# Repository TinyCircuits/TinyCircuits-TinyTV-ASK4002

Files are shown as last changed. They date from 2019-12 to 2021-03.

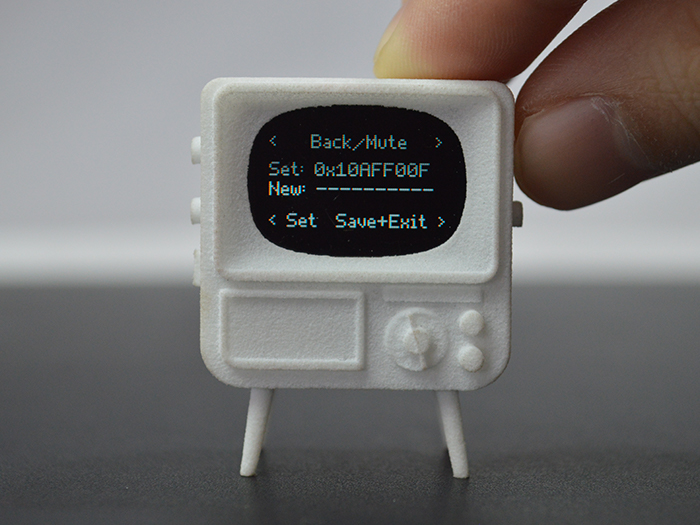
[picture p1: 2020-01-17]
images/TinyTV-Settings-Tutorial-Image-03.jpg

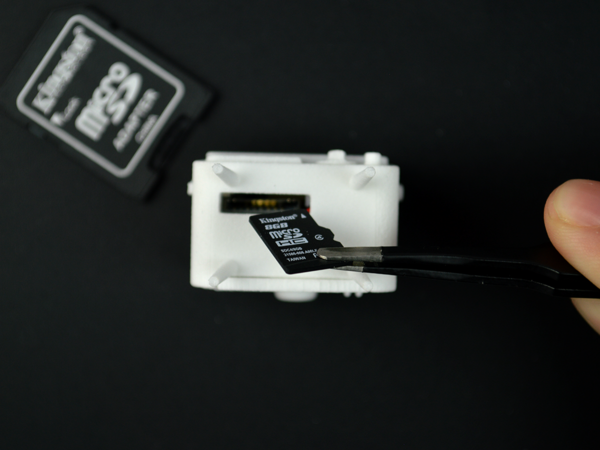
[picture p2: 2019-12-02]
images/TinyTV-Tutorial-Image-12.png

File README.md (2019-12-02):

# TinyCircuits TinyTV
# ASK4002

The design files are located under design_files/ for the TinyTV Remote, other design files can be found under the individual components' name on our GitHub. This Repo contains any files or documentation specific to the TinyTV.

Format is in Cadsoft Eagle format - Eagle version 6.2 was used for the original design.

For more infomation on this, check out the product page at TinyCircuits.com

# License:

Design by TinyCircuits.
All design files are released under the Creative Commons Attribution Share-Alike 3.0 License, see the following link for details: http://creativecommons.org/licenses/by-sa/3.0

All text above must be included in any redistribution or derived design

This project uses designs and concepts developed as part of the Arduino project and the LilyPad project.  The TinyCircuits design files themselves (schematics, PCB and libraries) are not directly derived from these works' design files and have been created new, however the concepts and basic architecture behind the TinyDuino and TinyLily products are derived and we thank the hard work of the organizations below for their contributions to open-source hardware:
  
Original Arduino Uno Design by Team Arduino

LilyPad Arduino Design by Leah Buechley and Sparkfun Electronics

Please support the open-source hardware community

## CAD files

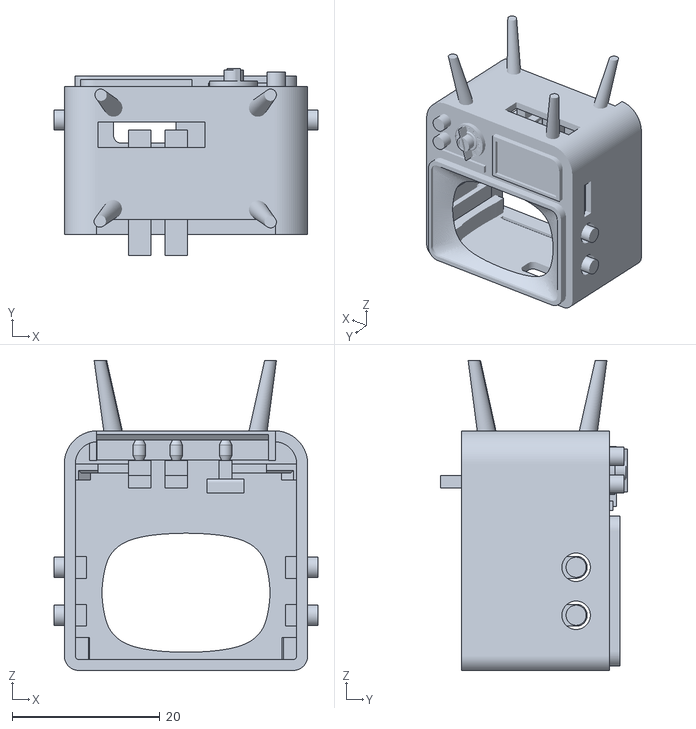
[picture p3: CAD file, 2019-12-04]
res/TinyTV_3D_files/TinyTVBodyV7.stl
35.7 x 25.4 x 42.0

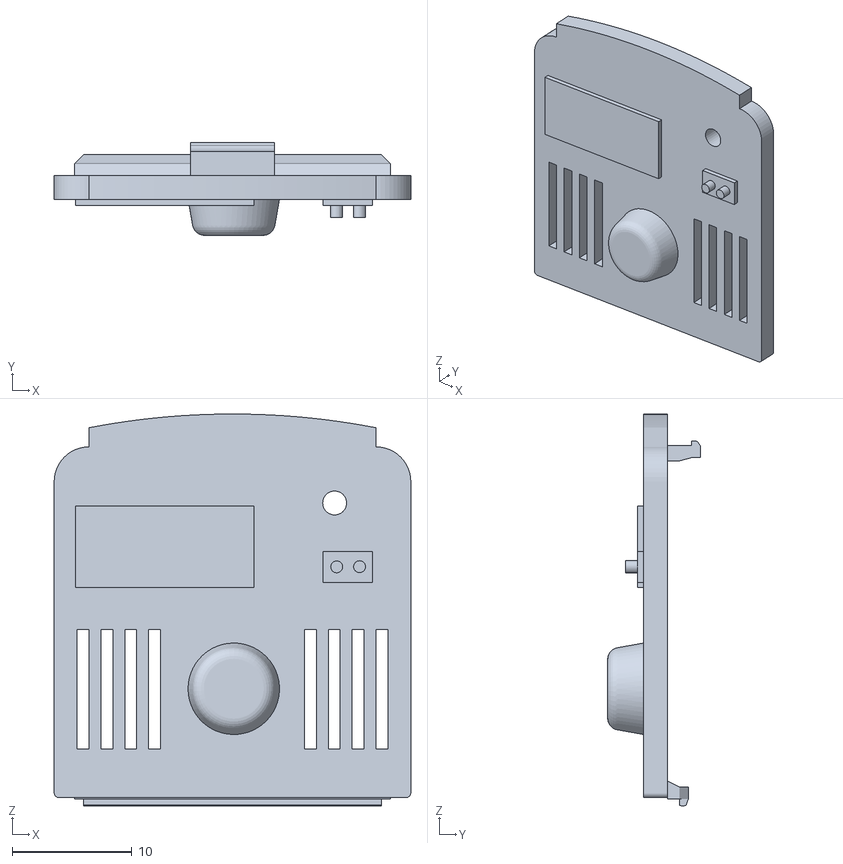
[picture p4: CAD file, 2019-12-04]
res/TinyTV_3D_files/RearPanelV7.stl
29.8 x 7.75 x 32.8

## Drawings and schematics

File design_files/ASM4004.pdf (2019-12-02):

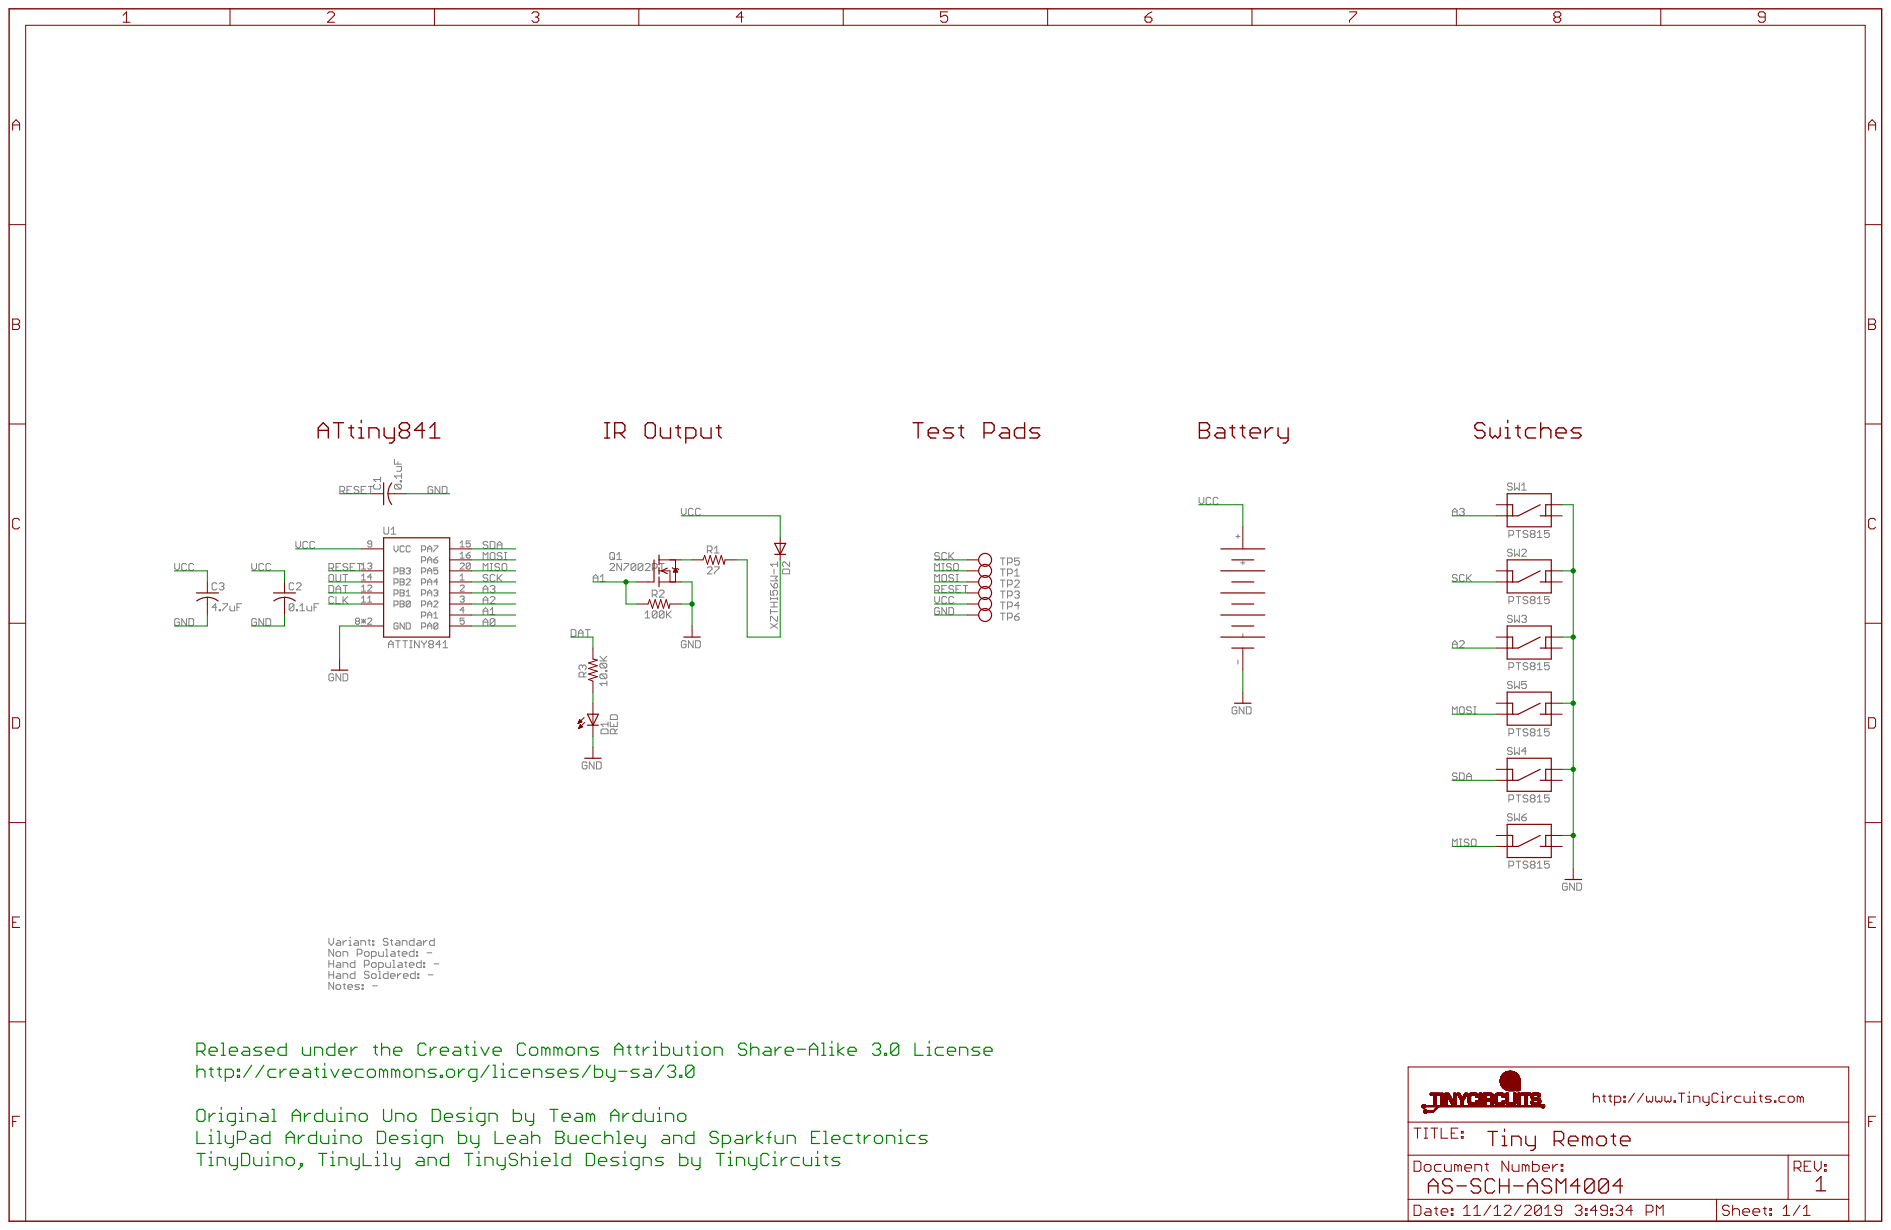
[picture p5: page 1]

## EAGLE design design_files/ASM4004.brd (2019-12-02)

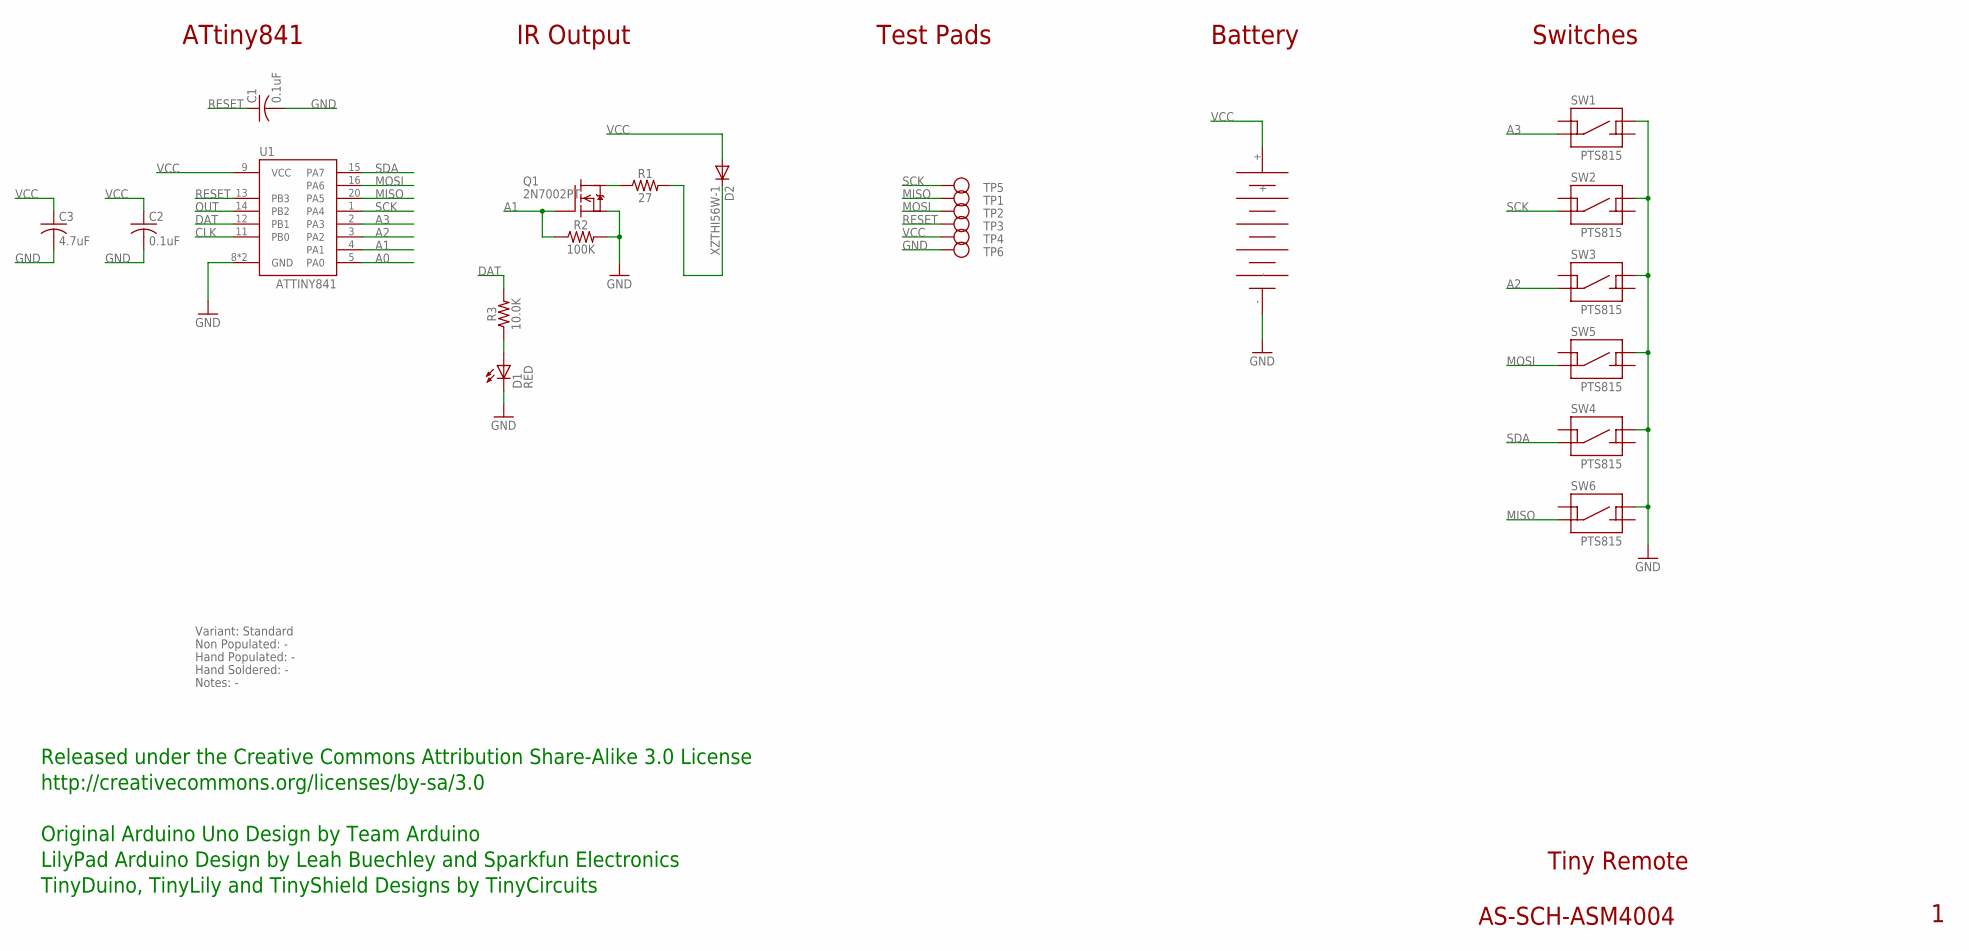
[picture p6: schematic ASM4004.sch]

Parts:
C1: 0.1uF; C0402; PARTNO AS-ITM-00008
C2: 0.1uF; C0402
C3: 4.7uF; C0402; PARTNO AS-ITM-00242
D1: RED; 0402_LED; PARTNO AS-ITM-00057
D2: XZTHI56W-1; LED_SIDE_3.0X1.0; PARTNO AS-ITM-00551
J2: 1225; COIN_1220_SMD; PARTNO AS-ITM-00468
Q1: 2N7002PT; SOT-416
R1: 27; 0402; PARTNO AS-ITM-00240
R2: 100K; 0402
R3: 10.0K; 0402; PARTNO AS-ITM-00032
SW1, SW2, SW3, SW4, SW5, SW6: PTS815; PARTNO AS-ITM-00544
TP1, TP2, TP3, TP4, TP5, TP6: TEST_POINT; TEST_POINT_1MM
U1: ATTINY841; VQFN-20

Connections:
A0: U1.5 (PA0)
A1: Q1.1 (G), R2.1, U1.4 (PA1)
A2: SW3.1, U1.3 (PA2)
A3: SW1.1, U1.2 (PA3)
CLK: U1.11 (PB0)
DAT: R3.2, U1.12 (PB1)
GND: C1.2, C2.2, C3.2, D1.2 (C), J2.-, Q1.2 (S), R2.2, SW1.4, SW2.4, SW3.4, SW4.4, SW5.4, SW6.4, TP6.P$1, U1.8 (GND), U1.PAD (GND)
MISO: SW6.1, TP1.P$1, U1.20 (PA5)
MOSI: SW5.1, TP2.P$1, U1.16 (PA6)
unnamed: Q1.3 (D), R1.1
unnamed: D2.C, R1.2
unnamed: D1.1 (A), R3.1
OUT: U1.14 (PB2)
RESET: C1.1, TP3.P$1, U1.13 (PB3)
SCK: SW2.1, TP5.P$1, U1.1 (PA4)
SDA: SW4.1, U1.15 (PA7)
VCC: C2.1, C3.1, D2.A, J2.+, TP4.P$1, U1.9 (VCC)

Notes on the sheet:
Tiny Remote
AS-SCH-ASM4004
Test Pads
ATtiny841
Battery
IR Output
Variant: Standard
Non Populated: -
Hand Populated: -
Hand Soldered: -
Notes: -
Switches
Released under the Creative Commons Attribution Share-Alike 3.0 License
http://creativecommons.org/licenses/by-sa/3.0
Original Arduino Uno Design by Team Arduino
TinyDuino, TinyLily and TinyShield Designs by TinyCircuits
LilyPad Arduino Design by Leah Buechley and Sparkfun Electronics

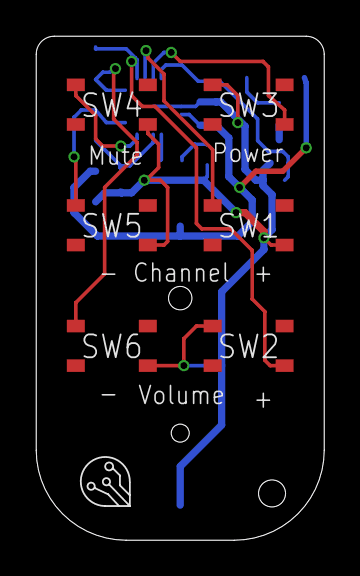
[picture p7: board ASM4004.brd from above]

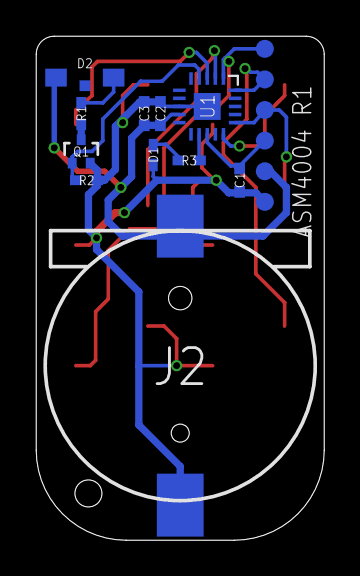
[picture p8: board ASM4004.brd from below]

Board: 2 copper layers, 16.0 x 28.0 mm, 24 parts (17 on the bottom side), 14 nets.

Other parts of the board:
U$1: DOCFIELD-TINYCIRCUITS-PCB

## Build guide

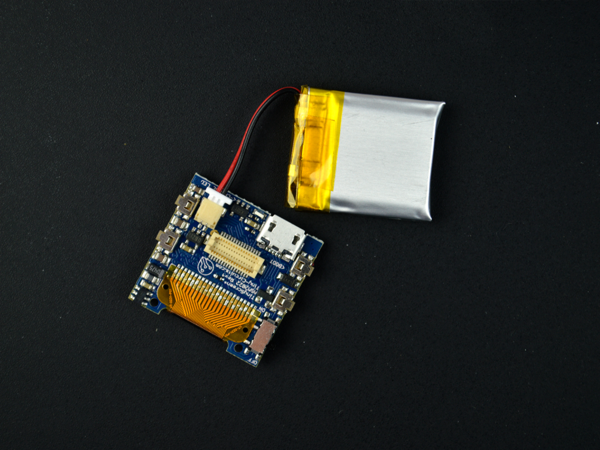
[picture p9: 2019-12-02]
images/TinyTV-Tutorial-Image-03.png

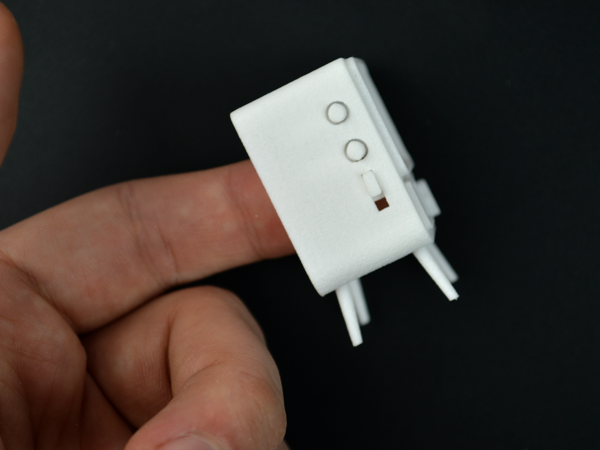
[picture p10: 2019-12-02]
images/TinyTV-Tutorial-Image-06.png

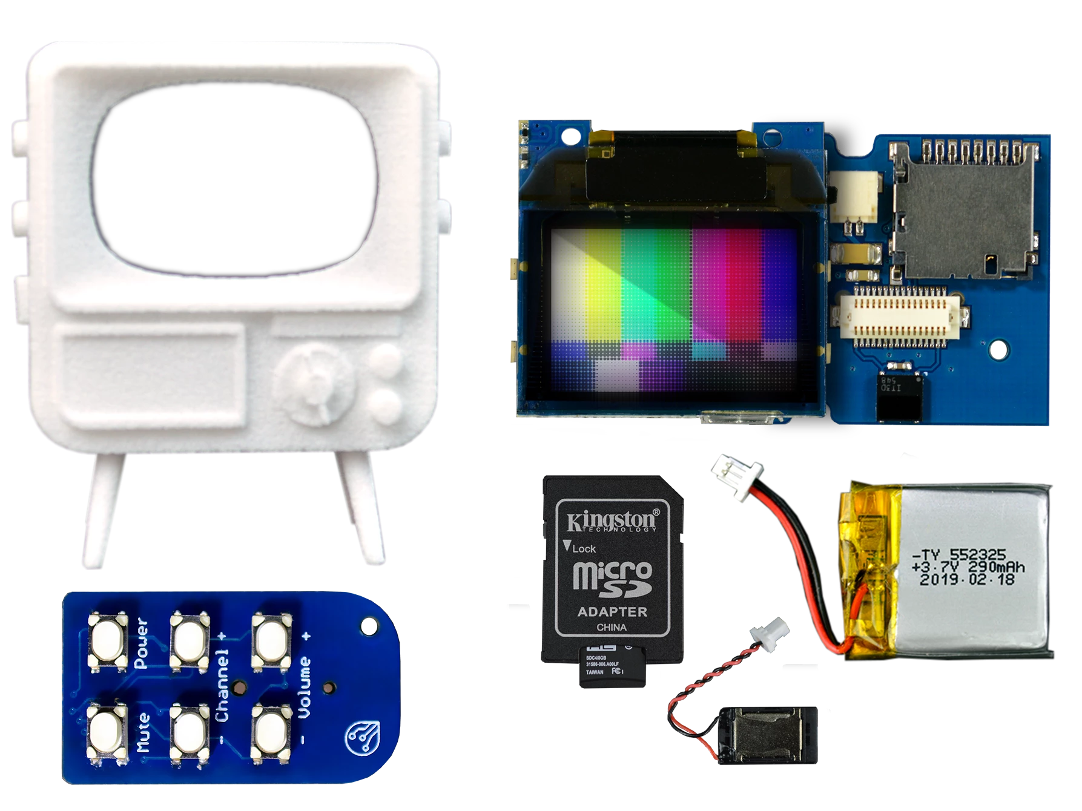
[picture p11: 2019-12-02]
images/TinyTV-Tutorial-Image-01.png

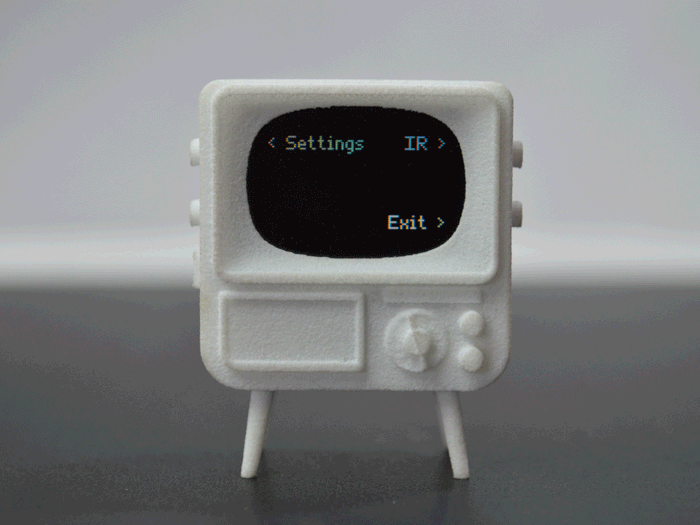
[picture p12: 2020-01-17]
images/TinyTV-Settings-Tutorial-Animation-01.gif

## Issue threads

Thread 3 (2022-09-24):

GCLK was not declared in scope.

patrick99e99, 2022-09-24:
I got your tinytv kit, and am following along your instructions:
http://learn.tinycircuits.com/Kits/Tiny-Video-Program/

When I open TinyTV.ino and click "verify" it says:
```
Arduino: 1.8.19 (Mac OS X), Board: "Arduino Uno"

/Users/patrick/Downloads/TinyTV/audio.ino: In function 'void tcConfigure(uint32_t)':
audio:7:3: error: 'GCLK' was not declared in this scope
   GCLK->CLKCTRL.reg = (uint16_t) (GCLK_CLKCTRL_CLKEN | GCLK_CLKCTRL_GEN_GCLK0 | GCLK_CLKCTRL_ID(GCM_TC4_TC5)) ;
   ^~~~
/Users/patrick/Downloads/TinyTV/audio.ino:7:3: note: suggested alternative: 'SCL'
   GCLK->CLKCTRL.reg = (uint16_t) (GCLK_CLKCTRL_CLKEN | GCLK_CLKCTRL_GEN_GCLK0 | GCLK_CLKCTRL_ID(GCM_TC4_TC5)) ;
   ^~~~
   SCL
audio:7:35: error: 'GCLK_CLKCTRL_CLKEN' was not declared in this scope
   GCLK->CLKCTRL.reg = (uint16_t) (GCLK_CLKCTRL_CLKEN | GCLK_CLKCTRL_GEN_GCLK0 | GCLK_CLKCTRL_ID(GCM_TC4_TC5)) ;
                                   ^~~~~~~~~~~~~~~~~~
audio:7:56: error: 'GCLK_CLKCTRL_GEN_GCLK0' was not declared in this scope
   GCLK->CLKCTRL.reg = (uint16_t) (GCLK_CLKCTRL_CLKEN | GCLK_CLKCTRL_GEN_GCLK0 | GCLK_CLKCTRL_ID(GCM_TC4_TC5)) ;
                                                        ^~~~~~~~~~~~~~~~~~~~~~
audio:7:97: error: 'GCM_TC4_TC5' was not declared in this scope
   GCLK->CLKCTRL.reg = (uint16_t) (GCLK_CLKCTRL_CLKEN | GCLK_CLKCTRL_GEN_GCLK0 | GCLK_CLKCTRL_ID(GCM_TC4_TC5)) ;
                                                                                                 ^~~~~~~~~~~
audio:7:81: error: 'GCLK_CLKCTRL_ID' was not declared in this scope
   GCLK->CLKCTRL.reg = (uint16_t) (GCLK_CLKCTRL_CLKEN | GCLK_CLKCTRL_GEN_GCLK0 | GCLK_CLKCTRL_ID(GCM_TC4_TC5)) ;
                                                                                 ^~~~~~~~~~~~~~~
audio:13:3: error: 'TC5' was not declared in this scope
   TC5->COUNT16.CTRLA.reg |= TC_CTRLA_MODE_COUNT16;
   ^~~
/Users/patrick/Downloads/TinyTV/audio.ino:13:3: note: suggested alternative: 'RC5'
   TC5->COUNT16.CTRLA.reg |= TC_CTRLA_MODE_COUNT16;
   ^~~
   RC5
audio:13:29: error: 'TC_CTRLA_MODE_COUNT16' was not declared in this scope
   TC5->COUNT16.CTRLA.reg |= TC_CTRLA_MODE_COUNT16;
                             ^~~~~~~~~~~~~~~~~~~~~
audio:16:29: error: 'TC_CTRLA_WAVEGEN_MFRQ' was not declared in this scope
   TC5->COUNT16.CTRLA.reg |= TC_CTRLA_WAVEGEN_MFRQ;
                             ^~~~~~~~~~~~~~~~~~~~~
audio:18:29: error: 'TC_CTRLA_PRESCALER_DIV1' was not declared in this scope
   TC5->COUNT16.CTRLA.reg |= TC_CTRLA_PRESCALER_DIV1;
                             ^~~~~~~~~~~~~~~~~~~~~~~
audio:20:40: error: 'SystemCoreClock' was not declared in this scope
   TC5->COUNT16.CC[0].reg = (uint16_t) (SystemCoreClock / sampleRate - 1);
                                        ^~~~~~~~~~~~~~~
audio:24:19: error: 'TC5_IRQn' was not declared in this scope
   NVIC_DisableIRQ(TC5_IRQn);
                   ^~~~~~~~
audio:24:3: error: 'NVIC_DisableIRQ' was not declared in this scope
   NVIC_DisableIRQ(TC5_IRQn);
   ^~~~~~~~~~~~~~~
audio:25:3: error: 'NVIC_ClearPendingIRQ' was not declared in this scope
   NVIC_ClearPendingIRQ(TC5_IRQn);
   ^~~~~~~~~~~~~~~~~~~~
audio:26:3: error: 'NVIC_SetPriority' was not declared in this scope
   NVIC_SetPriority(TC5_IRQn, 0);
   ^~~~~~~~~~~~~~~~
audio:27:3: error: 'NVIC_EnableIRQ' was not declared in this scope
   NVIC_EnableIRQ(TC5_IRQn);
   ^~~~~~~~~~~~~~
/Users/patrick/Downloads/TinyTV/audio.ino: In function 'bool tcIsSyncing()':
audio:37:10: error: 'TC5' was not declared in this scope
   return TC5->COUNT16.STATUS.reg & TC_STATUS_SYNCBUSY;
          ^~~
/Users/patrick/Downloads/TinyTV/audio.ino:37:10: note: suggested alternative: 'RC5'
   return TC5->COUNT16.STATUS.reg & TC_STATUS_SYNCBUSY;
          ^~~
          RC5
audio:37:36: error: 'TC_STATUS_SYNCBUSY' was not declared in this scope
   return TC5->COUNT16.STATUS.reg & TC_STATUS_SYNCBUSY;
                                    ^~~~~~~~~~~~~~~~~~
/Users/patrick/Downloads/TinyTV/audio.ino: In function 'void tcStartCounter()':
audio:44:3: error: 'TC5' was not declared in this scope
   TC5->COUNT16.CTRLA.reg |= TC_CTRLA_ENABLE;
   ^~~
/Users/patrick/Downloads/TinyTV/audio.ino:44:3: note: suggested alternative: 'RC5'
   TC5->COUNT16.CTRLA.reg |= TC_CTRLA_ENABLE;
   ^~~
   RC5
audio:44:29: error: 'TC_CTRLA_ENABLE' was not declared in this scope
   TC5->COUNT16.CTRLA.reg |= TC_CTRLA_ENABLE;
                             ^~~~~~~~~~~~~~~
/Users/patrick/Downloads/TinyTV/audio.ino: In function 'void tcReset()':
audio:51:3: error: 'TC5' was not declared in this scope
   TC5->COUNT16.CTRLA.reg = TC_CTRLA_SWRST;
   ^~~
/Users/patrick/Downloads/TinyTV/audio.ino:51:3: note: suggested alternative: 'RC5'
   TC5->COUNT16.CTRLA.reg = TC_CTRLA_SWRST;
   ^~~
   RC5
audio:51:28: error: 'TC_CTRLA_SWRST' was not declared in this scope
   TC5->COUNT16.CTRLA.reg = TC_CTRLA_SWRST;
                            ^~~~~~~~~~~~~~
/Users/patrick/Downloads/TinyTV/audio.ino: In function 'void tcDisable()':
audio:59:3: error: 'TC5' was not declared in this scope
   TC5->COUNT16.CTRLA.reg &= ~TC_CTRLA_ENABLE;
   ^~~
/Users/patrick/Downloads/TinyTV/audio.ino:59:3: note: suggested alternative: 'RC5'
   TC5->COUNT16.CTRLA.reg &= ~TC_CTRLA_ENABLE;
   ^~~
   RC5
audio:59:30: error: 'TC_CTRLA_ENABLE' was not declared in this scope
   TC5->COUNT16.CTRLA.reg &= ~TC_CTRLA_ENABLE;
                              ^~~~~~~~~~~~~~~
/Users/patrick/Downloads/TinyTV/audio.ino: In function 'void Audio_Handler()':
audio:72:10: error: 'DAC' was not declared in this scope
   while (DAC->STATUS.bit.SYNCBUSY == 1);
          ^~~
/Users/patrick/Downloads/TinyTV/audio.ino:72:10: note: suggested alternative: 'DEC'
   while (DAC->STATUS.bit.SYNCBUSY == 1);
          ^~~
          DEC
audio:81:3: error: 'DAC' was not declared in this scope
   DAC->DATA.reg =  dacOut;
   ^~~
/Users/patrick/Downloads/TinyTV/audio.ino:81:3: note: suggested alternative: 'DEC'
   DAC->DATA.reg =  dacOut;
   ^~~
   DEC
audio:94:3: error: 'TC5' was not declared in this scope
   TC5->COUNT16.INTFLAG.bit.MC0 = 1;
   ^~~
/Users/patrick/Downloads/TinyTV/audio.ino:94:3: note: suggested alternative: 'RC5'
   TC5->COUNT16.INTFLAG.bit.MC0 = 1;
   ^~~
   RC5
/Users/patrick/Downloads/TinyTV/settingsMenu.ino: In function 'void readCodes()':
settingsMenu:11:3: error: 'SerialUSB' was not declared in this scope
   SerialUSB.print("Opening IRCodes.txt.. ");
   ^~~~~~~~~
/Users/patrick/Downloads/TinyTV/settingsMenu.ino:11:3: note: suggested alternative: 'Serial'
   SerialUSB.print("Opening IRCodes.txt.. ");
   ^~~~~~~~~
   Serial
/Users/patrick/Downloads/TinyTV/settingsMenu.ino: In function 'void readSettings()':
settingsMenu:141:3: error: 'SerialUSB' was not declared in this scope
   SerialUSB.print("Opening Settings.txt.. ");
   ^~~~~~~~~
/Users/patrick/Downloads/TinyTV/settingsMenu.ino:141:3: note: suggested alternative: 'Serial'
   SerialUSB.print("Opening Settings.txt.. ");
   ^~~~~~~~~
   Serial
In file included from /Users/patrick/Downloads/TinyTV/videoPlayer.ino:33:0:
/Users/patrick/Downloads/TinyTV/videoPlayerEffects.h: In function 'void showStaticEffect()':
videoPlayerEffects.h:98:27: error: 'SysTick' was not declared in this scope
     uint8_t currentRand = SysTick->VAL;
                           ^~~~~~~
/Users/patrick/Downloads/TinyTV/videoPlayerEffects.h: In function 'void tinyTVtubeOff()':
videoPlayerEffects.h:188:33: error: 'SysTick' was not declared in this scope
           uint8_t currentRand = SysTick->VAL;
                                 ^~~~~~~
videoPlayerEffects.h:211:35: error: 'SysTick' was not declared in this scope
             uint8_t currentRand = SysTick->VAL;
                                   ^~~~~~~
/Users/patrick/Downloads/TinyTV/videoPlayer.ino: In function 'void playVideo()':
videoPlayer:194:59: error: 'SysTick' was not declared in this scope
           audioBuffer2[i] += (int8_t)((uint8_t)(((uint8_t)SysTick->VAL & 0x7F) | ((uint8_t)(SysTick->VAL << 7) & 0x80))) / 2;
                                                           ^~~~~~~
videoPlayer:202:59: error: 'SysTick' was not declared in this scope
           audioBuffer1[i] += (int8_t)((uint8_t)(((uint8_t)SysTick->VAL & 0x7F) | ((uint8_t)(SysTick->VAL << 7) & 0x80))) / 2;
                                                           ^~~~~~~
exit status 1
'GCLK' was not declared in this scope

This report would have more information with
"Show verbose output during compilation"
option enabled in File -> Preferences.
```

Also, when I go under Tools > Board, there is no TinyScreen+ option ...  And there is no `COM##(TinyScreen+)` option under port.

When I plug in the usb cable connected to the TV, I see an option under port appear `/dev/cu.usbmodem1101`

When I click board info I get:
```
BN: Unknown board
VID: 03EB
PID: 8009
SN: Upload any sketch to obtain it
```

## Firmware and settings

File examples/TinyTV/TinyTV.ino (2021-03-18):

//-------------------------------------------------------------------------------
//  TinyCircuits TinyTV Video Player
//
//  Changelog:
//  1.2.1 4 Jan 2021 - make lower left button configurable to "power off" or channel down
//  1.2.0 27 Nov 2019 - Add TinyTV mode with CRT effects, double buffered audio
//  1.1.0 15 Jul 2019 - Change to specifically support TinyScreen+ Video Player
//        Kit, adding IR receiver functionality and settings menu
//  1.0.3 15 Nov 2018 - Add option for TinyScreen+ button input
//  1.0.2 10 April 2017 - Cleanup, add messages about SD card/video detection
//  1.0.1 3 October 2016 - Add compatibility for new Arcade revision, change
//        folder structure for IDE compatibility
//  1.0.0 Initial release
//
//  Written by Ben Rose for TinyCircuits, http://TinyCircuits.com
//
//-------------------------------------------------------------------------------

#include <TinyScreen.h>
#include "SdFat.h"
#include <Wire.h>
#include <SPI.h>
#include "src/IRremote/IRremote.h"

// Default settings (Can be edited here or under the Settings menu on the TinyTV)
// To open TinyTV Settings: Turn TV off, then press and hold upper-right button
// while turning TV on. This should open the Settings & IR menu
long autoPlay = 1;
long showTimeBar = 1;
long loopVideo = 0;
long fullVolume = 1;
long tinyTVmode = 1;
long chanDwn = 0;

// IR NEC button codes (Can be edited here or under the IR menu on the TinyTV)
// The IR menu is found with the Settings menu. To toggle buttons for different
// functionality, open the IR menu, navigate to the desired button, press
// the button on the new remote, and save the NEC code.
long powerCode = 0x10AF8877;
long volUpCode = 0x10AF708F;
long volDownCode = 0x10AFB04F;
long chanUpCode = 0x10AF807F;
long chanDownCode = 0x10AF20DF;
long selectCode = 0x10AF00FF;
long returnCode = 0x10AFF00F;

int RECV_PIN = 3;

IRrecv irrecv(RECV_PIN);

TinyScreen display = TinyScreen(TinyScreenPlus);

SdFat sd;
SdFile dir;
SdFile vidFile;
uint8_t buffer[96 * 64 * 2];
uint16_t audioBuffer1[1024 * 2];
uint16_t audioBuffer2[1024 * 2];
int currentAudioBuffer = 0;
volatile int lastFilledAudioBuffer = 0;
volatile uint32_t sampleIndex = 0;

int currentFileNum = 0;
int doVideo = 0;
int foundValidVideo = 0;
char currentVideoName[50] = "No video found";

int printNicelyOffset = 0;
int printNicelyDir = 0;
unsigned long lastPrintNicelyOffsetChange = 0;
unsigned long printNicelyOffsetChangeInterval = 200;

volatile int volume = 5;
int maxVolume = 5;
int oldVolume = 5;

int isOff = false;


void setup(void) {
  analogWrite(A0, analogRead(A0));//Set audio output to avoid picking up noise, even if audio isn't used
  tcConfigure(30720);
  display.begin();
  display.setBitDepth(1);
  display.setFlip(true);
  display.setFont(thinPixel7_10ptFontInfo);
  display.initDMA();
  irrecv.enableIRIn(); // Start the receiver
  pinMode(RECV_PIN, INPUT_PULLUP);
  SPI.begin();
  delay(50);
  if (!sd.begin(10, SPI_FULL_SPEED)) {
    cardNotFound();
  }
  SPI.setClockDivider(0);
  if (display.getButtons(TSButtonUpperRight)) {
    delay(10);
    if (display.getButtons(TSButtonUpperRight)) {
      settingsMainMenu();
    }
  }
  readCodes();
  readSettings();
  if (!fullVolume) {
    volume = 3;
  }
  sd.vwd()->rewind();
  getNextFile();
  if (autoPlay || tinyTVmode) {
    startNewVideo();
  }
}

void loop() {
  if (tinyTVmode) {
    tinyTVloop();
  } else {
    videoPlayerLoop();
  }
}

void videoPlayerLoop() {

  decode_results results;

  long IRresult = 0;
  if (irrecv.decode(&results)) {
    irrecv.resume(); // Receive the next value
    //SerialUSB.print(results.decode_type);
    //SerialUSB.print(" ");
    //SerialUSB.print(results.bits);
    //SerialUSB.print(" ");
    //SerialUSB.println(results.value, HEX);
    IRresult = results.value;
  }
  if (!isOff && IRresult == volUpCode) {
    if (!isPaused())increaseVolumeRequest() ;
  }
  if (!isOff && IRresult == volDownCode) {
    if (!isPaused())decreaseVolumeRequest() ;
  }
  if (!isOff && (IRresult == chanUpCode || checkNewButtonPress(TSButtonLowerRight))) {
    if (isStopped() ) {
      //stopVideo();
      getNextFile();
      //startNewVideo();
    } else {
      seekForward();
    }
  }
  if (!isOff && IRresult == chanDownCode || checkNewButtonPress(TSButtonLowerLeft)) {
    if (isStopped() ) {
      //stopVideo();
      getPreviousFile();
      //startNewVideo();
    } else {
      seekBackward();
    }
  }
  if (!isOff && IRresult == selectCode || checkNewButtonPress(TSButtonUpperRight)) {
    if (isStopped()) {
      startNewVideo();
    } else {
      if (isPaused()) {
        requestUnPause();
      } else {
        requestPause();
        while (!isPaused())
          playVideo();
      }
    }
  }
  if (!isOff && IRresult == returnCode || checkNewButtonPress(TSButtonUpperLeft)) {
    if (!isStopped()) {
      stopVideo();
    }
  }
  if (IRresult == powerCode || checkNewButtonPress(TSButtonLowerLeft)) {
    if (!isOff) {
      if (!isStopped()) {
        requestPause();
        delay(10);
        display.endTransfer();
      }
      display.off();
      isOff = true;
    } else {
      display.on();
      if (!isStopped()) {
        display.goTo(0, 0);
        display.startData();
        requestUnPause();
      }
      isOff = false;
    }
  }
  if (doVideo  && !isOff && !isStopped()) {
    playVideo();
  }
  if (isStopped() && !isOff) {
    bufferVideoFrame();
    printNicely(currentVideoName);
    writeToDisplay();
  }
}


void tinyTVloop() {
  decode_results results;

  long IRresult = 0;
  if (irrecv.decode(&results)) {
    irrecv.resume(); // Receive the next value
    //SerialUSB.print(results.decode_type);
    //SerialUSB.print(" ");
    //SerialUSB.print(results.bits);
    //SerialUSB.print(" ");
    //SerialUSB.println(results.value, HEX);
    IRresult = results.value;
  }

  if (IRresult == volUpCode || checkNewButtonPress(TSButtonUpperRight)) {
    if (!isPaused())increaseVolumeRequest() ;
  }
  if (IRresult == volDownCode || checkNewButtonPress(TSButtonLowerRight)) {
    if (!isPaused())decreaseVolumeRequest() ;
  }
  if (IRresult == returnCode) {
    if (!isPaused())toggleMute();
  }
  if ((IRresult == chanUpCode || checkNewButtonPress(TSButtonUpperLeft)) && !isPaused()) {
    stopVideo();
    getNextFile();
    startNewVideo();
  }
if (IRresult == chanDownCode || (chanDwn && checkNewButtonPress(TSButtonLowerLeft)) && !isPaused()) {
    stopVideo();
    getPreviousFile();
    startNewVideo();
  }
  if (IRresult == powerCode || (!chanDwn && checkNewButtonPress(TSButtonLowerLeft))) {
    if (isPaused()) {
      display.on();
      display.goTo(0, 0);
      display.startData();
      requestUnPause();
    } else {
      requestPause();
      while (!isPaused())
        playVideo();
      delay(10);
      display.endTransfer();
      display.off();
    }
  }
  if (doVideo && !isPaused()) {
    playVideo();
  }
}

void bufferVideoFrame() {
  if (!vidFile.available())
    vidFile.rewind();
  vidFile.read(buffer, 96 * 64 * 2);
  vidFile.read((uint8_t*)audioBuffer1, 1024 * 2);
}

void writeToDisplay() {
  display.goTo(0, 0);
  display.startData();
  display.writeBuffer(buffer, 96 * 64 * 2);
  display.endTransfer();
}

void printCentered(int x, int y, char * stringToPrint) {
  int xPosition = x - ((int)display.getPrintWidth(stringToPrint) / 2);
  display.setCursor(xPosition, y);
  display.print(stringToPrint);
}

void displayCardNotFoundOptions() {
  display.clearScreen();
  display.setCursor(3, 8);
  display.print("< Settings ");
  display.setCursor(96 - 3 - display.getPrintWidth("IR >"), 8);
  display.print("IR >");
  display.setCursor(96 - 3 - display.getPrintWidth("Exit >"), 48);
  display.print("Exit >");
}

void settingsMainMenu() {
  displayCardNotFoundOptions();
  while (1) {
    if (checkNewButtonPress(TSButtonUpperRight)) {
      programCodes();
      displayCardNotFoundOptions();
    }
    if (checkNewButtonPress(TSButtonUpperLeft)) {
      changeSettings();
      displayCardNotFoundOptions();
    }
    if (checkNewButtonPress(TSButtonLowerRight)) {
      return;
    }
  }
}

void cardNotFound() {
  display.clearScreen();
  printCentered(48, 8, "Card not found!");
  printCentered(48, 25, "Insert card to");
  printCentered(48, 36, "change settings or");
  printCentered(48, 47, "program IR codes");
  unsigned long lastInit = millis();
  unsigned long initTimeout = 500;
  while (1) {
    if (millis() - lastInit > initTimeout) {
      lastInit = millis();
      if (sd.begin(10, SPI_FULL_SPEED)) {
        settingsMainMenu();
      }
    }
    decode_results results;
    long IRresult = 0;
    if (irrecv.decode(&results)) {
      IRresult = results.value;
      irrecv.resume(); // Receive the next value
      if (IRresult != 0xFFFFFFFF) {
        char resultString[20];
        sprintf(resultString, "0x%08X", IRresult);
        printCentered(44, 55, resultString);
      }
    }
  }
}

void getNextFile() {
  doVideo = 0;
  vidFile.close();
  int foundVideo = 0;
  while (!foundVideo) {
    dir.close();
    if (dir.openNext(sd.vwd(), O_READ)) {
      currentFileNum++;
    } else if (!foundValidVideo) {
      //This should mean there are no valid videos or SD card problem
      int xPosition = 48 - ((int)display.getPrintWidth("No video files!") / 2);
      display.setCursor(xPosition, 26 - 10);
      display.print("No video files!");
      xPosition = 48 - ((int)display.getPrintWidth("Place .TSV files") / 2);
      display.setCursor(xPosition, 26);
      display.print("Place .TSV files");
      xPosition = 48 - ((int)display.getPrintWidth("in main directory.") / 2);
      display.setCursor(xPosition, 26 + 10);
      display.print("in main directory.");
      while (1);
    } else {
      sd.vwd()->rewind();
      dir.openNext(sd.vwd(), O_READ);
      currentFileNum = 1;
    }
    if (dir.isFile()) {
      char fileName[100];
      memset(fileName, 0, 100);
      dir.getName(fileName, 50);
      if (!strcmp(fileName + strlen(fileName) - 4, ".tsv")) {
        dir.close();
        if (vidFile.open(fileName, O_READ)) {
          doVideo = 1;
          foundValidVideo = 1;
          foundVideo = 1;
        }
      }
    }
  }
  vidFile.getName(currentVideoName, 50);
  currentVideoName[strlen(currentVideoName) - 4] = '\0';
  printNicelyOffset = 0;
  printNicelyDir = 0;
  lastPrintNicelyOffsetChange = millis();
}

void getPreviousFile() {
  doVideo = 0;
  vidFile.close();
  int foundVideo = 0;
  while (!foundVideo) {
    if (currentFileNum > 1) {
      currentFileNum--;
    } else {
      currentFileNum = 100;
      int i;
      for (i = 1; i < currentFileNum; i++) {
        dir.close();
        if (!dir.openNext(sd.vwd(), O_READ))break;
      }
      currentFileNum = i;
    }
    sd.vwd()->rewind();
    int i;
    for (i = 1; i <= currentFileNum; i++) {
      dir.close();
      if (!dir.openNext(sd.vwd(), O_READ))break;
    }
    if (dir.isFile()) {
      char fileName[100];
      memset(fileName, 0, 100);
      dir.getName(fileName, 50);
      if (!strcmp(fileName + strlen(fileName) - 4, ".tsv")) {
        dir.close();
        if (vidFile.open(fileName, O_READ)) {
          doVideo = 1;
          foundVideo = 1;
        }
      }
    }
  }
  vidFile.getName(currentVideoName, 50);
  currentVideoName[strlen(currentVideoName) - 4] = '\0';
  printNicelyOffset = 0;
  printNicelyDir = 0;
  lastPrintNicelyOffsetChange = millis();
}

void printNicely(char * name) {
  int yOffset = 34;
  for (int y = yOffset + 0; y < yOffset + 12; y++) {
    for (int x = 0; x < 96; x++) {
      ((uint16_t *)buffer)[(y * 96) + x] = (((uint16_t *)buffer)[(y * 96) + x] >> 2) & 0xE739; //0xEF7B
    }
  }
  char displayName[50];
  strcpy(displayName, name + printNicelyOffset);

  int xPosition = 48 - ((int)display.getPrintWidth(displayName) / 2);

  if (millis() > lastPrintNicelyOffsetChange + printNicelyOffsetChangeInterval) {
    lastPrintNicelyOffsetChange = millis();
    if (xPosition < 9) {
      printNicelyOffset++;
    } else {
      printNicelyOffset = 0;
    }
  }

  while (xPosition < 9) {
    displayName[strlen(displayName) - 1] = '\0';
    xPosition = 48 - ((int)display.getPrintWidth(displayName) / 2);
  }

  for (int y = yOffset + 1; y < yOffset + 15; y++) {
    putString(y, xPosition, yOffset + 1, displayName, buffer + (96 * 2 * y), thinPixel7_10ptFontInfo);
  }
  char chbuf[] = "<";
  for (int y = yOffset + 1; y < yOffset + 15; y++) {
    putString(y, 1, yOffset + 1, chbuf, buffer + (96 * 2 * y), thinPixel7_10ptFontInfo);
  }
  chbuf[0] = '>';
  for (int y = yOffset + 1; y < yOffset + 15; y++) {
    putString(y, 87 + 5, yOffset + 1, chbuf, buffer + (96 * 2 * y), thinPixel7_10ptFontInfo);
  }
}

void putString(int y, int fontX, int fontY, char * string, uint8_t * buff, const FONT_INFO & fontInfo) {
  const FONT_CHAR_INFO* fontDescriptor = fontInfo.charDesc;
  int fontHeight = fontInfo.height;
  if (y >= fontY && y < fontY + fontHeight) {
    const unsigned char* fontBitmap = fontInfo.bitmap;
    int fontFirstCh = fontInfo.startCh;
    int fontLastCh = fontInfo.endCh;
    //if(!_fontFirstCh)return 1;
    //if(ch<_fontFirstCh || ch>_fontLastCh)return 1;
    //if(_cursorX>xMax || _cursorY>yMax)return 1;
    int stringChar = 0;
    int ch = string[stringChar++];
    while (ch) {
      uint8_t chWidth = pgm_read_byte(&fontDescriptor[ch - fontFirstCh].width);
      int bytesPerRow = chWidth / 8;
      if (chWidth > bytesPerRow * 8)
        bytesPerRow++;
      unsigned int offset = pgm_read_word(&fontDescriptor[ch - fontFirstCh].offset) + (bytesPerRow * fontHeight) - 1;

      for (uint8_t byte = 0; byte < bytesPerRow; byte++) {
        uint8_t data = pgm_read_byte(fontBitmap + offset - (y - fontY) - ((bytesPerRow - byte - 1) * fontHeight));
        uint8_t bits = byte * 8;
        for (int i = 0; i < 8 && (bits + i) < chWidth; i++) {
          if (data & (0x80 >> i)) {
            buff[(fontX) * 2] = 0xFFFF >> 8;
            buff[(fontX) * 2 + 1] = 0xFFFF;
            // setPixelInBuff(y,16+fontX,0);
            //lineBuffer[16+fontX]=0;
          } else {
            //SPDR=_fontBGcolor;
          }
          fontX++;
        }
      }
      fontX += 1;
      ch = string[stringChar++];
    }
  }
}

uint8_t buttonState = TSButtonUpperLeft | TSButtonUpperRight | TSButtonLowerLeft | TSButtonLowerRight;

bool checkNewButtonPress(uint8_t mask) {
  uint8_t currentButtonState = display.getButtons(mask);
  bool returnval = false;
  if (((mask & buttonState) == 0) && ((mask & currentButtonState) == mask)) {
    delay(10);
    currentButtonState = display.getButtons(mask);
    if (((mask & buttonState) == 0) && ((mask & currentButtonState) == mask)) {
      returnval = true;
    }
  }
  buttonState &= (~mask);
  buttonState |= currentButtonState;
  return returnval;
}

int showPlaying = 0;

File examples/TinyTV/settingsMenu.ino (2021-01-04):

char codeNames[][15] = {"   On/Off   ", "   Vol Up   ", "   Vol Down   ", "  Up/Right  ", " Down/Left ", "  Select  ", "  Back/Mute  "};
long * codeList[] = {&powerCode, &volUpCode, &volDownCode, &chanUpCode, &chanDownCode, &selectCode, &returnCode};
int numCodes = 7;
int currentCode = 0;

void readCodes() {
  SdFile codeFile;
  codeFile.open("IRCodes.txt", FILE_READ);
  currentCode = 0;
  SerialUSB.print("Opening IRCodes.txt.. ");
  if (codeFile.available()) {
    SerialUSB.println("opened! ");
    while (codeFile.available()) {
      if (codeFile.read() == '0') {
        if (codeFile.read() == 'x') {
          char strBuf[20] = "            ";
          uint32_t tempInt = 0;
          codeFile.read(strBuf, 8);
          tempInt = strtoul(strBuf, NULL, 16);
          *codeList[currentCode] = tempInt;
          /*
            SerialUSB.print(codeNames[currentCode]);
            SerialUSB.print("read as: ");
            SerialUSB.print(strBuf);
            SerialUSB.print("strtoul output: ");
            SerialUSB.println(tempInt,HEX);
          */
          currentCode++;
          if (currentCode >= numCodes)codeFile.close();
        }
      }
    }
  } else {
    SerialUSB.println("error! ");
  }
  codeFile.close();
}

void writeCodes() {
  SdFile codeFile;
  codeFile.open("IRCodes.txt", FILE_WRITE | O_CREAT);
  if (codeFile.isOpen()) {
    codeFile.seekSet(0);
    currentCode = 0;
    while (currentCode < numCodes) {
      char strBuf[20];
      sprintf(strBuf, "0x%08X\r\n", *codeList[currentCode]);
      codeFile.print(strBuf);
      currentCode++;
    }
    codeFile.sync();
  }
  codeFile.close();
}

void programCodes() {
  display.clearScreen();
  delay(100);
  if (!sd.begin(10, SPI_FULL_SPEED)) {
    if (!sd.begin(10, SPI_FULL_SPEED)) {
      printCentered(48, 30, "Card error!");
      while (1);
    }
  }
  readCodes();
  currentCode = 0;
  display.setCursor(3, 8);
  display.print("<");
  display.setCursor(96 - 3 - 6, 8);
  display.print(">");
  display.setCursor(96 - 3 - display.getPrintWidth("Save+Exit >"), 48);
  display.print("Save+Exit >");

  display.setCursor(3, 48);
  display.print("< Set");

  char resultString[20] = "----------";
  decode_results results;
  long IRresult = 0;
  while (1) {
    if (checkNewButtonPress(TSButtonUpperRight)) {
      currentCode++;
      if (currentCode >= numCodes) {
        currentCode = 0;
      }
      IRresult = 0;
    }
    if (checkNewButtonPress(TSButtonUpperLeft)) {
      currentCode--;
      if (currentCode < 0) {
        currentCode = numCodes - 1;
      }
      IRresult = 0;
    }
    if (checkNewButtonPress(TSButtonLowerLeft)) {
      if (IRresult) {
        *codeList[currentCode] = IRresult;
      }
    }
    if (checkNewButtonPress(TSButtonLowerRight)) {
      writeCodes();
      return;
    }
    if (irrecv.decode(&results)) {
      irrecv.resume(); // Receive the next value
      if (results.value != 0xFFFFFFFF) {
        IRresult = results.value;
      }
    }

    char currentCodeString[20] = "0x00000000";
    sprintf(currentCodeString, "0x%08X", *codeList[currentCode]);
    if (IRresult) {
      sprintf(resultString, "0x%08X", IRresult);
    } else {
      sprintf(resultString, "----------");
    }
    printCentered(48, 8, codeNames[currentCode]);
    display.setCursor(3, 22);
    display.print("Set: ");
    display.print(currentCodeString);
    display.setCursor(3, 32);
    display.print("New: ");
    display.print(resultString);
  }
}




char settingNames[][15] = {" TinyTV Mode ", "  Auto Play  ", "  Show Time  ", " Loop Video ", "  Full Vol  ", "  Chan Dwn  "};
long * settingList[] = {&tinyTVmode, &autoPlay, &showTimeBar, &loopVideo, &fullVolume, &chanDwn};
int numSettings = 6;
int currentSetting = 0;

void readSettings() {
  SdFile settingsFile;
  settingsFile.open("Settings.txt", FILE_READ);
  currentSetting = 0;
  SerialUSB.print("Opening Settings.txt.. ");
  if (settingsFile.available()) {
    SerialUSB.println("opened! ");
    while (settingsFile.available()) {
      if (settingsFile.read() == '0') {
        if (settingsFile.read() == 'x') {
          char strBuf[20] = "            ";
          uint32_t tempInt = 0;
          settingsFile.read(strBuf, 8);
          tempInt = strtoul(strBuf, NULL, 16);
          *settingList[currentSetting] = tempInt;
          currentSetting++;
          if (currentSetting >= numSettings)settingsFile.close();
        }
      }
    }
  } else {
    SerialUSB.println("error! ");
  }
  settingsFile.close();
}

void writeSettings() {
  SdFile settingsFile;
  settingsFile.open("Settings.txt", FILE_WRITE | O_CREAT);
  if (settingsFile.isOpen()) {
    settingsFile.seekSet(0);
    currentSetting = 0;
    while (currentSetting < numSettings) {
      char strBuf[20];
      sprintf(strBuf, "0x%08X\r\n", *settingList[currentSetting]);
      settingsFile.print(strBuf);
      currentSetting++;
    }
    settingsFile.sync();
  }
  settingsFile.close();
}
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

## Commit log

2019-12-04 tv files
    [RearPanelV7.stl, TinyTVBodyV7.stl]
2020-05-18 new button image
2021-01-04 make lower left button configurable to "power off" or channel down
2021-01-06 fix chanDwn bug - short circuit eval needed
    [TinyTV.ino]
